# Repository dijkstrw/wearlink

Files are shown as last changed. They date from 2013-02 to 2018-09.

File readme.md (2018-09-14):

# Wearlink

## Introduction

While looking for a new winter coat I stumbled on a Taiwanese manufacturer
selling a black and blue winter coat with keys on the sleeve.

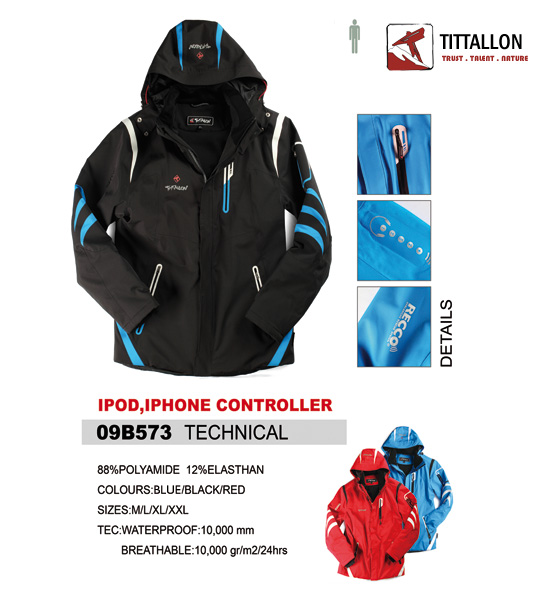
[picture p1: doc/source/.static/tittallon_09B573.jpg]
Coat and keys


The keys legend betray their intended purpose: volume control, play/pause and
forward/reverse. I listen to podcasts on my android phone in the car and on the
bike, and this would make a great way to control those even when wearing
gloves!

It turns out that the real keypad is glued to the inside of the sleeve, just
under the outer coat layers. A ruggedized two-wire cable connected the keypad
to a 2.5mm TRS in the left chest pocket.

The keypad is manufactured by [FibreTronic](http://fibretronic.com) under the
moniker connectedwear. They sell a range of keypads (my coat has the
[KP2-5SH](http://fibretronic.com/connectedwear/KP25SH) )  and a range of controllers
that can be connected to the keypad. Naturally none of their controllers work
for me. So I set out to build my own under these requirements:

* No internal battery. Nothing sucks more than being interrupted whilst
  enjoying total worl^H^H^H^Hcoat domination.

* Default interface to the phone. Ideally no programming on the phone, because
  this somewhat guarantees project longevity.

## My solution

A controller that pretends to be a usb keyboard and emits multimedia keys for
connectedwear keypresses. The controller is powered via usb straight from the
phone.

While looking around for good donor projects I stumbled on the
[EasyLogger](http://www.obdev.at/products/vusb/easylogger.html). A project that
uses a 8-pin ATTiny45 with just a few passives to emulate an usb keyboard that
reports back values read by the micro's ADC.

So after:

* Modifying the code to emit multimedia keys
* Connecting the ADC to the coat keys using a 2.5mm trs jack
* Connecting the ATTiny to the phone using a ghetto 4 wire to usb plug

I can now control music on my phone using the keys on my coat. Hooray!

## Schematic & PCB
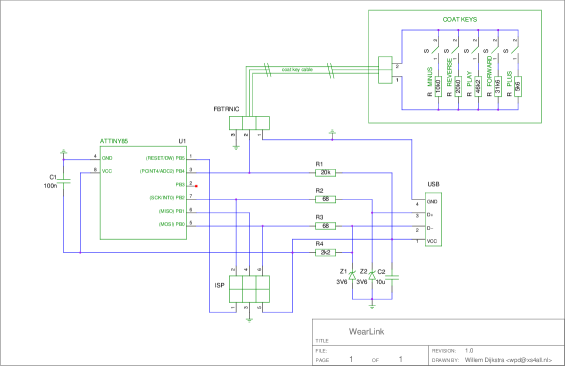
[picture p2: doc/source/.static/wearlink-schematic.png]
Geda schematic

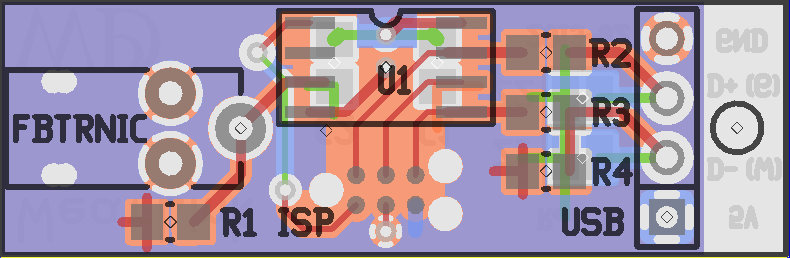
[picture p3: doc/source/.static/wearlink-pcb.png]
PCB

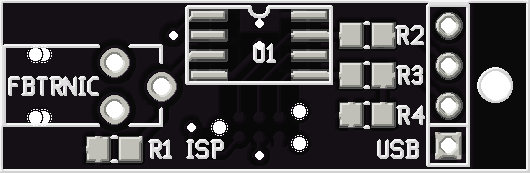
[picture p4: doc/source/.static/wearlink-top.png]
Front of PCB

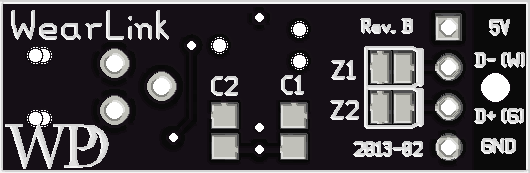
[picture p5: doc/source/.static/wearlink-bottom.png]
Back of the PCB


Note that a TagConnect header is used for ISP.

## Directory structure

* src: an avr-gcc project, targetting the ATTiny85 including the
  [Virtual USB port of AVR microcontrollers](http://www.obdev.at/products/vusb/index.html) driver.

* schematic: a GEDA/gschem schematic

* layout: a GEDA/pcb layout for a 34x11mm board.

## Notes for next time

* Do not waste time on PIC microcontrollers. Their development chain leaves
  much to be desired; horrid include files that define and undefine an absolute
  forest of variables, a compiler that keeps telling you how much space can be
  saved if you would only BUY now, and a memory architecture from the previous
  century.

* Determine power draw early in the project for battery constrained
  applications. My current solution comes in at a 18mAh, which is not that
  great.

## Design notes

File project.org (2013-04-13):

* Measurements of coat
  Setup:
  - 2.5mm female trs
    T = yellow
    R = red
    S = blue
  - 2.5mm male trs
    T = yellow
    R = white
    S = blue
** Resistance
   Connect F 2.5mmTRS to male 2.5mm of coat
   resistance between yellow/tip and blue/ground:
   | key | resistance, Ohm |
   |-----+-----------------|
   | +   | 5.575 k         |
   | >1  | 31.67 k         |
   | 11< | 46.28 k         |
   | 1<  | 19.96 k         |
   | -   | 10.018 k        |
** Current
   Connect F 2.5mm TRS to male 2.5mm of coat
   Connect F TRS to M TRS with fluke 8600A (uA) between yellow lines
   Connect M TRS to coat widget
   Connect coat widget to phone
   | key | current in uA |
   |-----+---------------|
   | +   | 106           |
   | >1  | 55.1          |
   | 11< | 43.21         |
   | 1<  | 70.12         |
   | -   | 91.39         |
** Voltage
   using scope: voltage between yellow/tip and blue/sleeve was 3V but fluctuated +-200mV

* Calculations
  Determine the adc register value at a $Vcc, an $bits bit ADC, into an $rbits
  bit ADC register. The ADC is connected between the fibretronic buttons and a
  $Rl that tied to the Vcc supply.

  With Vcc at 5V, and a 25k resistor to each rail with the coat keys inbetween:
  | ! | Key     |       Rk |  Vadc |     Adc | Register |
  |---+---------+----------+-------+---------+----------|
  | # | none    |        0 | 5.000 |    1024 |      256 |
  | # | minus   |    10000 | 3.333 |     683 |      171 |
  | # | rev     |    20000 | 2.500 |     512 |      128 |
  | # | play    |    46200 | 1.511 |     309 |       77 |
  | # | forward |    31600 | 1.938 |     397 |       99 |
  | # | plus    |     5600 | 3.906 |     800 |      200 |
  |---+---------+----------+-------+---------+----------|
  | $ |         | Rl=20000 | Vcc=5 | bits=10 |  rbits=8 |
  #+TBLFM: $4=$Vcc-($Rk/($Rl+$Rk))*$Vcc;%.3f::$5=$Vadc/($Vcc/2^$bits);%.0f::$6=$Adc/(2^($bits-$rbits));%.0f

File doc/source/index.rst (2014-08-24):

Introduction
------------
While looking for a new winter coat I stumbled on a Taiwanese manufacturer
selling a black and blue winter coat with keys on the sleeve. The coat and keys:



The keys legend betray their intended purpose: volume control, play/pause and
forward/reverse. I listen to podcasts on my android phone in the car and on the
bike, and this would make a great way to control those even when wearing
gloves!

It turns out that the real keypad is glued to the inside of the sleeve, just
under the outer coat layers. A ruggedized two-wire cable connected the keypad
to a 2.5mm TRS in the left chest pocket.

The keypad is manufactured by `FibreTronic <http://fibretronic.com>`_ under the
moniker connectedwear. They sell a range of keypads (my coat has the `KP2-5SH
<http://fibretronic.com/connectedwear/KP25SH>`_) and a range of controllers
that can be connected to the keypad. Naturally none of their controllers work
for me. So I set out to build my own under these requirements:

* No internal battery. Nothing sucks more than being interrupted whilst
  enjoying total worl^H^H^H^Hcoat domination.

* Default interface to the phone. Ideally no programming on the phone, because
  this somewhat guarantees project longevity.

My solution
-----------

A controller that pretends to be a usb keyboard and emits multimedia keys for
connectedwear keypresses. The controller is powered via usb straight from the
phone.

While looking around for good donor projects I stumbled on the `EasyLogger
<http://www.obdev.at/products/vusb/easylogger.html>`_. A project that uses a
8-pin ATTiny45 with just a few passives to emulate an usb keyboard that reports
back values read by the micro's ADC.

So after:

* Modifying the code to emit multimedia keys
* Connecting the ADC to the coat keys using a 2.5mm trs jack
* Connecting the ATTiny to the phone using a ghetto 4 wire to usb plug

I can now control music on my phone using the keys on my coat. Hooray!

Schematic
~~~~~~~~~


Printed Circuit Board
~~~~~~~~~~~~~~~~~~~~~


Front of the pcb:



Back of the pcb:



Note that a TagConnect header is used for ISP.

Main source file
~~~~~~~~~~~~~~~~
During development I looked around for good information about how to emit multimedia keys. In case I ever forget:

.. literalinclude:: ../../src/firmware/main.c
   :language: c

Download
--------
:download:`wearlink-1.0.tar.gz <wearlink-1.0.tar.gz>`

This contains the directories:

* src: an avr-gcc project, targetting the ATTiny85 including the `Virtual USB port of
  AVR microcontrollers <http://www.obdev.at/products/vusb/index.html>`_ driver.

* schematic: a GEDA/gschem schematic

* layout: a GEDA/pcb layout for a 34x11mm board.

Notes for next time
-------------------

* Do not waste time on PIC microcontrollers. Their development chain leaves
  much to be desired; horrid include files that define and undefine an absolute
  forest of variables, a compiler that keeps telling you how much space can be
  saved if you would only BUY now, and a memory architecture from the previous
  century.

* Determine power draw early in the project for battery constrained
  applications. My current solution comes in at a 18mAh, which is not that
  great.

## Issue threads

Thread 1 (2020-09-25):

Wearlink fabrication

zjobra, 2020-09-25:
I've uploaded wearlink to pcbhubs for manufacturing order
https://pcbhubs.com/newpcb/16010209055f6da3e9c1e43

dijkstrw, 2020-09-28:
Good to hear you are interested in this project.

Are you aware of the [new version](https://github.com/dijkstrw/wearlink_nrf58122) of this board that uses BLE instead of a wired connection? This versions' wired connection always broke for me over time due to repeated wire movements while wearing the coat.

Closed 2020-09-28.

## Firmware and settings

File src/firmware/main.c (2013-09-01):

/*
 * Wearlink
 *
 * A fibretronic keypad to usb multimedia key code translator
 *
 * (c) 2013 Willem Dijkstra
 *
 * Based V-USB "EasyLogger", (c) 2006 OBJECTIVE DEVELOPMENT Software GmbH.
 */

#include <avr/io.h>
#include <avr/wdt.h>
#include <avr/eeprom.h>
#include <avr/interrupt.h>
#include <avr/pgmspace.h>
#include <util/delay.h>

#include "usbdrv.h"
#include "oddebug.h"

/*
 * Pin assignment:
 * PB4 = analog input (ADC2)
 * PB0, PB2 = USB data lines
*/

static uchar    reportBuffer[1];    /* buffer for HID reports */
static uchar    idleRate;           /* in 4 ms units */
static uchar    adcPending;
static uchar    mmKey;

const PROGMEM char usbHidReportDescriptor[USB_CFG_HID_REPORT_DESCRIPTOR_LENGTH] = { /* USB report descriptor */
    0x05, 0x01,                    // USAGE_PAGE (Generic Desktop)
    0x09, 0x06,                    // USAGE (Keyboard)
    0xa1, 0x01,                    // COLLECTION (Application)

    0x95, 0x01,                    //   REPORT_COUNT(1)
    0x75, 0x08,                    //   REPORT_SIZE(8)
    0x15, 0x00,                    //   LOGICAL_MINIMUM(0)
    0x25, 0xff,                    //   LOGICAL_MAXIMUM(1)
    0x05, 0x0C,                    //   USAGE_PAGE (Consumer)
    0x19, 0x00,                    //   USAGE_MINIMUM (0)
    0x29, 0xff,                    //   USAGE_MAXIMUM (0xff)
    0x81, 0x00,                    //   INPUT (Data, Array); Media Keys

    0xc0                           // END_COLLECTION
};
/* We use a simplifed keyboard report descriptor with 1 entry for multimedia
 * keys. We do not support modifiers, status leds or normal keys.
 */

/*
   Vcc is tied to the ADC pin using a 20k resistor. From there we connect to
   the coat keys and finally to ground. The different coat keys make a
   resistive divider at the ADC node. This table calculates the expected ADC
   measurement given the known resistance and an expected deviation of +-9%.

   #+ORGTBL: SEND keymarks orgtbl-to-generic :lstart "   { " :lend " }," :sep ", " :skip 2 :skipcols (3 4 5 6)
   | ! | Key           |       Rk |  Vadc |     Adc | Adc 8bit |    A-D% | A+D% |
   |---+---------------+----------+-------+---------+----------+---------+------|
   | # | KEY_NONE      | 10000000 | 4.990 |    1022 |      256 |     233 |  255 |
   | # | KEY_VOLUMEDEC |    10000 | 1.667 |     341 |       85 |      77 |   93 |
   | # | KEY_REWIND    |    20000 | 2.500 |     512 |      128 |     116 |  140 |
   | # | KEY_PLAY      |    46200 | 3.489 |     715 |      179 |     163 |  195 |
   | # | KEY_FORWARD   |    31600 | 3.062 |     627 |      157 |     143 |  171 |
   | # | KEY_VOLUMEINC |     5600 | 1.094 |     224 |       56 |      51 |   61 |
   |---+---------------+----------+-------+---------+----------+---------+------|
   | $ |               | Rl=20000 | Vcc=5 | bits=10 |  rbits=8 | dev=.09 |      |
   #+TBLFM: $4=$Vcc-($Rl/($Rk+$Rl))*$Vcc;%.3f::$5=$Vadc/($Vcc/2^$bits);%.0f::$6=$Adc/(2^($bits-$rbits));%.0f::$7=max($6-($dev*$6),0);%.0f::$8=min($6+($dev*$6),255);%0.f
*/

/* Codes to mark multimedia key presses, see usb.org's HID-usage-tables
 * document, chapter 15.
 */
#define KEY_NONE            0x00
#define KEY_VOLUMEINC       0xe9
#define KEY_VOLUMEDEC       0xea
#define KEY_REWIND          0xb4
#define KEY_FORWARD         0xb3
#define KEY_PLAY            0xcd

#define NUMKEYS             6

struct keymark {
    uchar key;
    uchar low;
    uchar high;
};

const struct keymark keymark[NUMKEYS] = {
/* BEGIN RECEIVE ORGTBL keymarks */
   { KEY_NONE, 233, 255 },
   { KEY_VOLUMEDEC, 77, 93 },
   { KEY_REWIND, 116, 140 },
   { KEY_PLAY, 163, 195 },
   { KEY_FORWARD, 143, 171 },
   { KEY_VOLUMEINC, 51, 61 },
/* END RECEIVE ORGTBL keymarks */
};

/* ------------------------------------------------------------------------- */

static void buildReport(void)
{
    reportBuffer[0] = mmKey;
}

static void evaluateADC(unsigned int value)
{
    uchar   i;
    uchar   v = (value >> 2) & 0xff;

    for (i = 0; i < NUMKEYS; i++) {
        if ((keymark[i].low <= v) && (v <= keymark[i].high)) {
            mmKey = keymark[i].key;
            break;
        }
    }
}

static void adcPoll(void)
{
    if(adcPending && !(ADCSRA & _BV(ADSC))){
        adcPending = 0;
        evaluateADC(ADC);
    }
}

static void timerPoll(void)
{
    static uchar timerCnt;

    if(TIFR & _BV(TOV1)){
        TIFR = _BV(TOV1);           /* clear overflow */
        if(++timerCnt >= 15){       /* ~ 1/4 s interval */
            timerCnt = 0;
            adcPending = 1;
            ADCSRA |= _BV(ADSC);    /* start next conversion */
        }
    }
}

static void timerInit(void)
{
    /* Select prescale as 1k; overflow rate is then 16M5 / (1k * 256) = 64.45 Hz */
    TCCR1 = _BV(CS13) | _BV(CS11) | _BV(CS10);
}

static void adcInit(void)
{
    /* Vref=Vcc, no AREF, no left right adjust, measure ADC2 */
    ADMUX = _BV(MUX1);
    /* Enable ADC, no interrupt, no free run, prescale = clock/128 */
    ADCSRA = _BV(ADEN) | _BV(ADPS2) | _BV(ADPS1) | _BV(ADPS0);
}

uchar	usbFunctionSetup(uchar data[8])
{
    usbRequest_t    *rq = (void *)data;

    usbMsgPtr = reportBuffer;
    if ((rq->bmRequestType & USBRQ_TYPE_MASK) == USBRQ_TYPE_CLASS) {
        /* class request type */
        if (rq->bRequest == USBRQ_HID_GET_REPORT) {
            /* wValue: ReportType (highbyte), ReportID (lowbyte) */
            /* we only have one report type, so don't look at wValue */
            buildReport();
            return sizeof(reportBuffer);
        } else if (rq->bRequest == USBRQ_HID_GET_IDLE) {
            usbMsgPtr = &idleRate;
            return 1;
        } else if (rq->bRequest == USBRQ_HID_SET_IDLE) {
            idleRate = rq->wValue.bytes[1];
        }
    } else {
        /* no vendor specific requests implemented */
    }
    return 0;
}

/* Calibrate the RC oscillator to 8.25 MHz. The core clock of 16.5 MHz is
 * derived from the 66 MHz peripheral clock by dividing. Our timing reference
 * is the Start Of Frame signal (a single SE0 bit) available immediately after
 * a USB RESET. We first do a binary search for the OSCCAL value and then
 * optimize this value with a neighboorhod search.
 * This algorithm may also be used to calibrate the RC oscillator directly to
 * 12 MHz (no PLL involved, can therefore be used on almost ALL AVRs), but this
 * is wide outside the spec for the OSCCAL value and the required precision for
 * the 12 MHz clock! Use the RC oscillator calibrated to 12 MHz for
 * experimental purposes only!
 */
static void calibrateOscillator(void)
{
    uchar       step = 128;
    uchar       trialValue = 0, optimumValue;
    int         x, optimumDev, targetValue = (unsigned)(1499 * (double)F_CPU / 10.5e6 + 0.5);

    /* do a binary search: */
    do{
        OSCCAL = trialValue + step;
        x = usbMeasureFrameLength();    /* proportional to current real frequency */
        if(x < targetValue)             /* frequency still too low */
            trialValue += step;
        step >>= 1;
    } while (step > 0);
    /* We have a precision of +/- 1 for optimum OSCCAL here */
    /* now do a neighborhood search for optimum value */
    optimumValue = trialValue;
    optimumDev = x; /* this is certainly far away from optimum */
    for (OSCCAL = trialValue - 1; OSCCAL <= trialValue + 1; OSCCAL++){
        x = usbMeasureFrameLength() - targetValue;
        if (x < 0)
            x = -x;
        if (x < optimumDev){
            optimumDev = x;
            optimumValue = OSCCAL;
        }
    }
    OSCCAL = optimumValue;
}

void    usbEventResetReady(void)
{
    /* Disable interrupts during oscillator calibration since
     * usbMeasureFrameLength() counts CPU cycles.
     */
    cli();
    calibrateOscillator();
    sei();
    eeprom_write_byte(0, OSCCAL);   /* store the calibrated value in EEPROM */
}

int main(void)
{
    uchar   i;
    uchar   sendClear = 0;
    uchar   calibrationValue;

    calibrationValue = eeprom_read_byte(0); /* calibration value from last time */
    if (calibrationValue != 0xff){
        OSCCAL = calibrationValue;
    }
    odDebugInit();
    usbDeviceDisconnect();

    for (i = 0;i < 20; i++){  /* 300 ms disconnect */
        _delay_ms(15);
    }

    usbDeviceConnect();
    wdt_enable(WDTO_1S);

    timerInit();
    adcInit();
    usbInit();

    sei();
    for (;;){    /* main event loop */
        wdt_reset();
        usbPoll();

        /* First round will fire for an mmKey, and second round for a sendClear */
        if (usbInterruptIsReady()) {
            if (mmKey || sendClear) {
                buildReport();
                mmKey = 0;
                sendClear ^= 1;
                usbSetInterrupt(reportBuffer, sizeof(reportBuffer));
            }
        }
        timerPoll();
        adcPoll();
    }
    return 0;
}

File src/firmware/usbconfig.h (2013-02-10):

/* Name: usbconfig.h
 * Project: AVR USB driver
 * Author: Christian Starkjohann
 * Creation Date: 2007-06-23
 * Tabsize: 4
 * Copyright: (c) 2007 by OBJECTIVE DEVELOPMENT Software GmbH
 * License: GNU GPL v2 (see License.txt) or proprietary (CommercialLicense.txt)
 * This Revision: $Id$
 */

#ifndef __usbconfig_h_included__
#define __usbconfig_h_included__

/* ---------------------------- Hardware Config ---------------------------- */

#define USB_CFG_IOPORTNAME      B
/* This is the port where the USB bus is connected. When you configure it to
 * "B", the registers PORTB, PINB and DDRB will be used.
 */
#define USB_CFG_DMINUS_BIT      0
/* This is the bit number in USB_CFG_IOPORT where the USB D- line is connected.
 * This may be any bit in the port.
 */
#define USB_CFG_DPLUS_BIT       2
/* This is the bit number in USB_CFG_IOPORT where the USB D+ line is connected.
 * This may be any bit in the port. Please note that D+ must also be connected
 * to interrupt pin INT0!
 */
#define USB_CFG_CLOCK_KHZ       (F_CPU/1000)
/* Clock rate of the AVR in MHz. Legal values are 12000, 16000 or 16500.
 * The 16.5 MHz version of the code requires no crystal, it tolerates +/- 1%
 * deviation from the nominal frequency. All other rates require a precision
 * of 2000 ppm and thus a crystal!
 * Default if not specified: 12 MHz
 */

/* ----------------------- Optional Hardware Config ------------------------ */

/* #define USB_CFG_PULLUP_IOPORTNAME   D */
/* If you connect the 1.5k pullup resistor from D- to a port pin instead of
 * V+, you can connect and disconnect the device from firmware by calling
 * the macros usbDeviceConnect() and usbDeviceDisconnect() (see usbdrv.h).
 * This constant defines the port on which the pullup resistor is connected.
 */
/* #define USB_CFG_PULLUP_BIT          4 */
/* This constant defines the bit number in USB_CFG_PULLUP_IOPORT (defined
 * above) where the 1.5k pullup resistor is connected. See description
 * above for details.
 */

/* --------------------------- Functional Range ---------------------------- */

#define USB_CFG_HAVE_INTRIN_ENDPOINT    1
/* Define this to 1 if you want to compile a version with two endpoints: The
 * default control endpoint 0 and an interrupt-in endpoint 1.
 */
#define USB_CFG_HAVE_INTRIN_ENDPOINT3   0
/* Define this to 1 if you want to compile a version with three endpoints: The
 * default control endpoint 0, an interrupt-in endpoint 1 and an interrupt-in
 * endpoint 3. You must also enable endpoint 1 above.
 */
#define USB_CFG_IMPLEMENT_HALT          0
/* Define this to 1 if you also want to implement the ENDPOINT_HALT feature
 * for endpoint 1 (interrupt endpoint). Although you may not need this feature,
 * it is required by the standard. We have made it a config option because it
 * bloats the code considerably.
 */
#define USB_CFG_INTR_POLL_INTERVAL      10
/* If you compile a version with endpoint 1 (interrupt-in), this is the poll
 * interval. The value is in milliseconds and must not be less than 10 ms for
 * low speed devices.
 */
#define USB_CFG_IS_SELF_POWERED         0
/* Define this to 1 if the device has its own power supply. Set it to 0 if the
 * device is powered from the USB bus.
 */
#define USB_CFG_MAX_BUS_POWER           20
/* Set this variable to the maximum USB bus power consumption of your device.
 * The value is in milliamperes. [It will be divided by two since USB
 * communicates power requirements in units of 2 mA.]
 */
#define USB_CFG_IMPLEMENT_FN_WRITE      0
/* Set this to 1 if you want usbFunctionWrite() to be called for control-out
 * transfers. Set it to 0 if you don't need it and want to save a couple of
 * bytes.
 */
#define USB_CFG_IMPLEMENT_FN_READ       0
/* Set this to 1 if you need to send control replies which are generated
 * "on the fly" when usbFunctionRead() is called. If you only want to send
 * data from a static buffer, set it to 0 and return the data from
 * usbFunctionSetup(). This saves a couple of bytes.
 */
#define USB_CFG_IMPLEMENT_FN_WRITEOUT   0
/* Define this to 1 if you want to use interrupt-out (or bulk out) endpoint 1.
 * You must implement the function usbFunctionWriteOut() which receives all
 * interrupt/bulk data sent to endpoint 1.
 */
#define USB_CFG_HAVE_FLOWCONTROL        0
/* Define this to 1 if you want flowcontrol over USB data. See the definition
 * of the macros usbDisableAllRequests() and usbEnableAllRequests() in
 * usbdrv.h.
 */
#ifndef __ASSEMBLER__
extern void usbEventResetReady(void);
#endif
#define USB_RESET_HOOK(isReset)             if(!isReset){usbEventResetReady();}
/* This macro is a hook if you need to know when an USB RESET occurs. It has
 * one parameter which distinguishes between the start of RESET state and its
 * end.
 */
#define USB_CFG_HAVE_MEASURE_FRAME_LENGTH   1
/* define this macro to 1 if you want the function usbMeasureFrameLength()
 * compiled in. This function can be used to calibrate the AVR's RC oscillator.
 */
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

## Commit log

2011-12-21 what I sent to tag connect.com
    [example.fab.gbr, example.top.gbr, example.topmask.gbr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]
2012-10-07 Added first schematic, not taking programming the device into account.
    [wearlink.sch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]
2012-10-13 Added Microchip example projects, will investigate and prune some more later
    [ImageDecoderConfig.txt]
2012-10-14 Updated schematic, redid measurements
    [wearlink.sch]
2012-10-17 USB device is now enumerated by host
2012-10-21 Made adc calculations
2013-02-02 Started new schematic based on the easylogger
    [easylogger.sch, wearlink.sch]
2013-02-03 Reworked schematic into ATtiny85
    [wearlink.sch]
2013-02-03 cleaned up remaining microchip cruft
    [ImageDecoderConfig.txt]
2013-02-03 Added programming header and first footprints.
    [wearlink.sch]
2013-02-10 Added radio table with the resistances, and broke away old adc logging code.
    [main.c]
2013-02-10 Added USB tables and started with pcb layout
2013-02-10 Removed easylogger sources.
    [easylogger.sch]
2013-02-15 Trying to rescheme the old schematic
    [wearlink2.sch]
2013-02-15 Added Lumberg 1501-05 connector footprint
2013-02-15 Added lumberg and diodes to see whats what in the layout
2013-02-16 Little pin changes + added netnames
    [wearlink.sch]
2013-02-16 horsing about on the pcb
2013-02-17 Updated schematic, commit before compacting layout
    [wearlink.sch]
2013-02-17 Good layout
    [wearlink.sch]
2013-02-18 Added usb cable hole for strain relief
2013-02-18 Preparing for fabrication
    [wearlink.GBL, wearlink.GBO, wearlink.GBS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]
2013-02-18 Added tag connect connector rewire schematic.
    [connectors.sch]
2013-02-20 Added SOD110 for footprint testing
2013-02-23 Last minute DRC modifications + sent to manufacturer.
    [wearlink.GBL, wearlink.GBO, wearlink.GBS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]
2013-02-23 Added power reduction statements
2013-02-24 Noticed that my SO8 pads were to small, respun and resent a rev B to itead.
    [wearlink2.sch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]
2013-02-24 Added annotation to show what footprint will fit an attiny85-S[UH]
2013-02-24 Add the empty zero keypress in every key event to ensure that my android phone sends the keypress to the active application.
    Without this keypress the current application does not see the keypress and android's default music application is started.
2013-03-17 Added quick AVR ISP IDC6 -> WL ISP IDC6 pcb as a soldering template
2013-04-13 Restructured project directory in preparation for documentation writing.
    [connectors.sch, wearlink.sch]

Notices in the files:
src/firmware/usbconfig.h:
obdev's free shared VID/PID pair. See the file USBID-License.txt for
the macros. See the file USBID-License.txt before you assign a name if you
